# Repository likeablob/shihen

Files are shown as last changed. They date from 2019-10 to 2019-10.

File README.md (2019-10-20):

<p align="center">
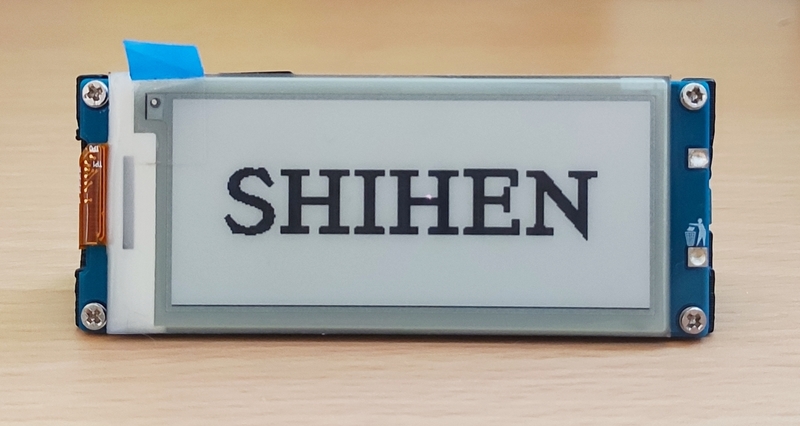
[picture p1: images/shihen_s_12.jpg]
  
</p>

**SHIHEN** is a device which colors your everyday (a bit).  
Have a glimpse of your favorite poems, quotes or scenes of a movie.

## Features
- On board RTC offers 2+ years of battery life.([in theory](https://blc.now.sh/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))
- By using [a dedicated Web-based converter](https://shihen.now.sh/), you can quickly show any texts and videos on the device.

## Gallery
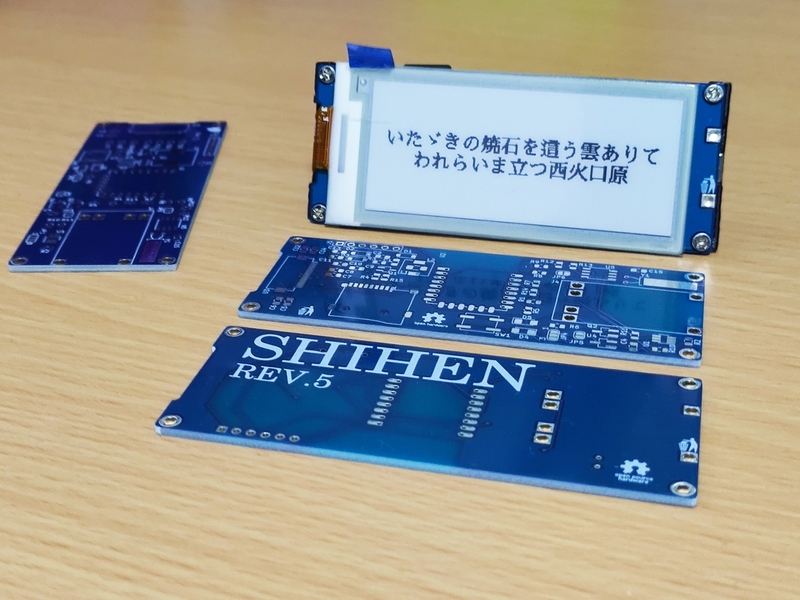
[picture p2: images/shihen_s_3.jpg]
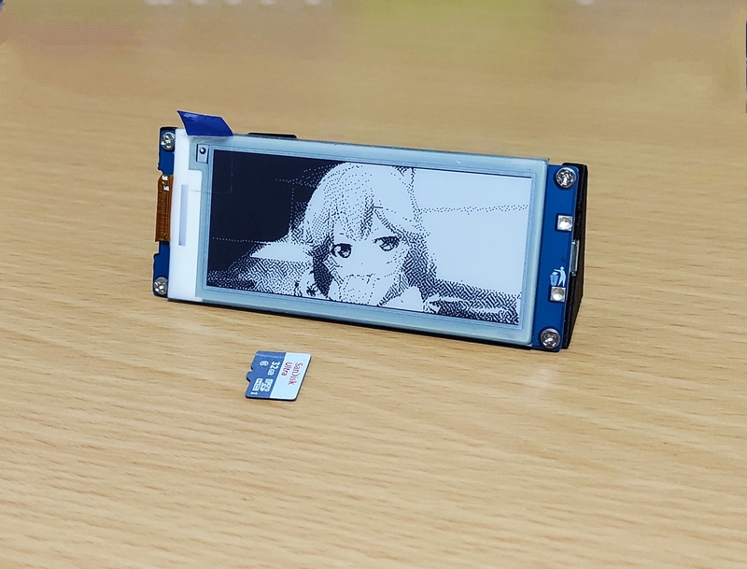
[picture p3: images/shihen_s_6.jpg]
|    |  |
| :---: | :---: |
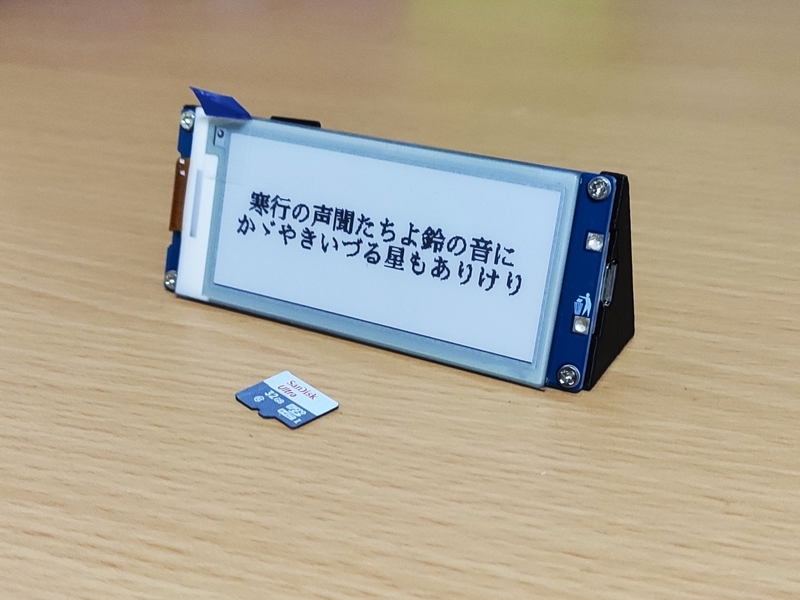
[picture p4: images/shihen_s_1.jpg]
|  |  |
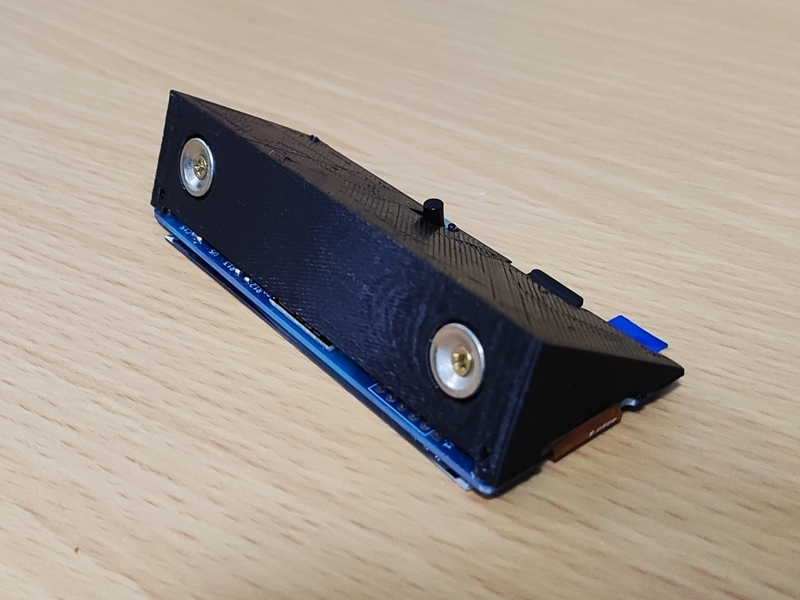
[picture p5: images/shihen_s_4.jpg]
|    | |

## Project structure
- [`pio/`](./pio) - code for the firmware(PlatformIO)
- [`kicad/`](./kicad) - PCB design (KiCad)
- [`openscad/`](./openscad) - models for the 3D-printable case. (OpenSCAD)
- https://github.com/likeablob/shihen-webui - code for the WebUI(Nuxt.js + Vuetify)

## Build Instructions
WIP

## BOM
WIP

## Refs
- Hackaday.io: https://hackaday.io/project/168039-shihen

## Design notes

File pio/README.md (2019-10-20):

# SHIHEN/firmware
It's built on top of [esp8266/Arduino](https://github.com/esp8266/Arduino).

## Prerequisites
- [PlatformIO](https://platformio.org/)

## Build
- `Ctrl+Alt+B` in your editor, or 
```bash
$ pio run
```

## Upload
- `Ctrl + Alt + U` in your editor, or 
```bash
$ pio run -t upload
```
- ***Tips:*** Don't forget to comment out the lines below to do ISP(UART) programming.
```bash
# platform.ini
upload_port = ${env:main.device_name}.local
upload_protocol = espota
```
### ISP port (J1) pin definitions:
| Pin No. | Board | USB Serial |
| --- | --- | --- |
| 1 | 5V(LDO_IN) | 5V |
| 2 | ESP_RESET(RST)  | RTS |
| 3 | ESP_BOOT(GPIO0) | DTR |
| 4 | GND | GND |
| 5 | ESP_TX(UART TX) | RX |
| 6 | ESP_RX(UART RX) | TX |

### Acknowledgments
- Please refer to
  - [platformio.ini](./platformio.ini)
  - [lib/](./lib)

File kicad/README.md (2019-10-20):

# SHIHEN/PCB

<p align="center">
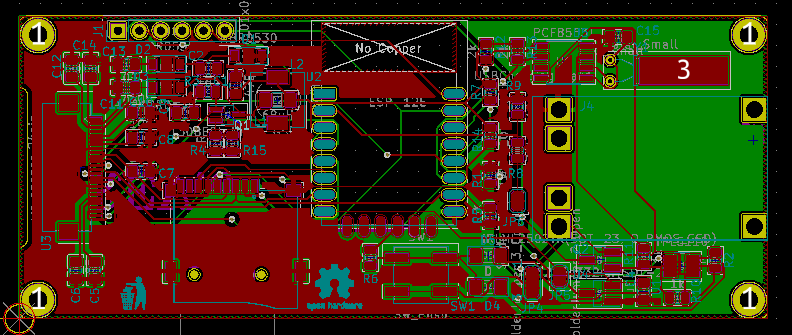
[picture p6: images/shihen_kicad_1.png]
  
</p>

## Prerequisites
- [KiCAD](http://kicad-pcb.org/) v5.0.1

## Credits
- [jdunmire]'s [ESP-12E.kicad_mod](./lib_ext/ESP-12E.kicad_mod): borrowed from [jdunmire/kicad-ESP8266](https://github.com/jdunmire/kicad-ESP8266/tree/70e6530de5e3cae4ae77a4bca7d73b20a0af6baf)
- [Joan_Sparky]'s [Conn_uSDcard.kicad_mod](./lib_ext/Conn_uSDcard.kicad_mod): borrowed from  https://forum.kicad.info/t/microsd-component-footprint-help/3095/5

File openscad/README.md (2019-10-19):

<p align="center">
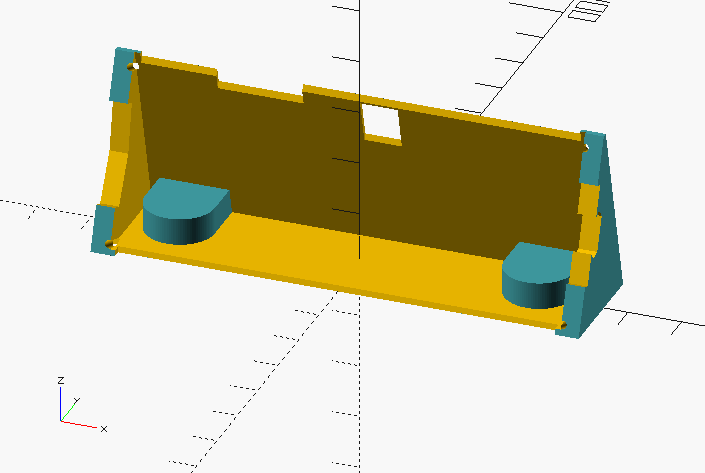
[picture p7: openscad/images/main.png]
  
</p>

## Print conditions
- PLA, 0.2 mm, 180 ℃
- `shihen-case` [[stl](./shihen-case.stl)]: Rotate so that the -YX(backbanel) plane is facing down.

## Dependencies
- openscad-nightly (`20181009T230242.gitf3de0e27+2416.1`)

## Build
```sh
$ make -j4
```

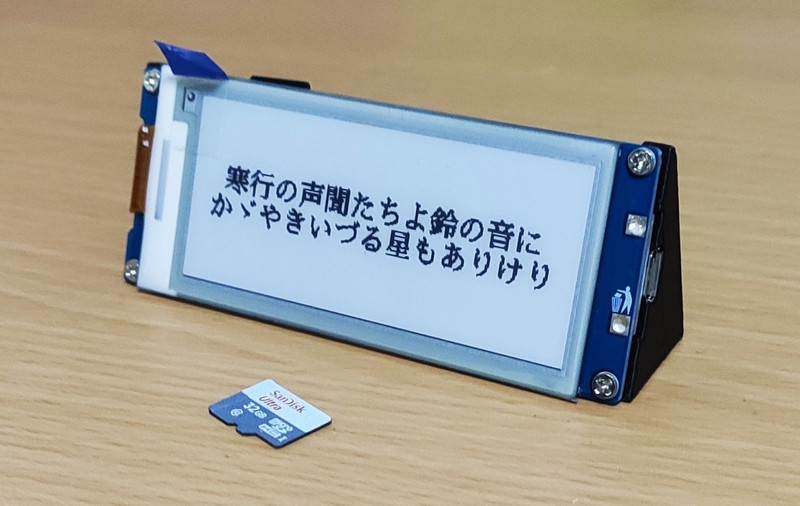
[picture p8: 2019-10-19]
images/shihen_s_1_tr.jpg

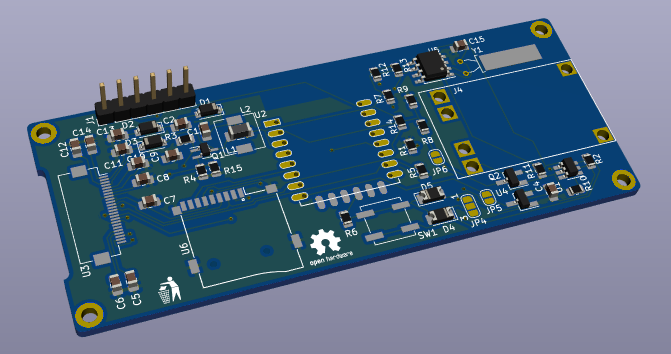
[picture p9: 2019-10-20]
images/shihen_kicad_2.png

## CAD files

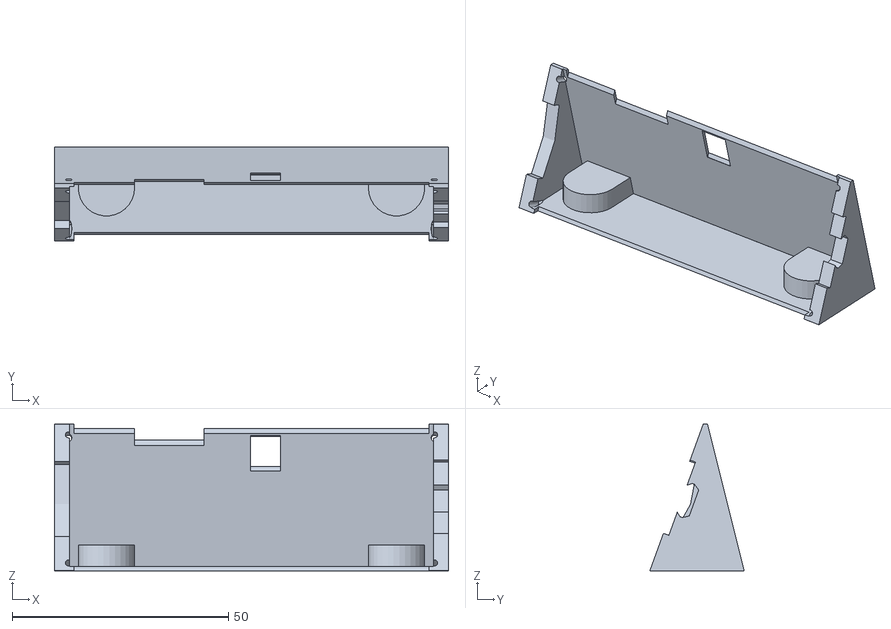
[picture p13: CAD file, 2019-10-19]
openscad/shihen-case.stl
91.0 x 21.8 x 33.8

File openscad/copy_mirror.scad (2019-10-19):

// Borrowed from http://forum.openscad.org/Wish-mirror-copy-true-td10681.html
module copy_mirror(vec=[0,1,0])
{
    children();
    mirror(vec) children();
}

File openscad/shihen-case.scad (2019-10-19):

$fn=30;

include <copy_mirror.scad>

BOARD_X = 83+2*2;
BOARD_Y = 27.5+2*2;

DISP_X=89;
DISP_Y=36;
DISP_Z=1.5;

DISP_E_X=68.3;
DISP_E_Y=30.5;

CASE_X=DISP_X+2;
CASE_Y=DISP_Y+2;
CASE_Z=DISP_Z+6;

SIDE_B_EDGE_Y=3.5*2;
SIDE_B_YPOS=4;

BOARD_ANGLE=80;

module display() {
  translate([0, 0, DISP_Z/2])
  cube(size=[DISP_X, DISP_Y, DISP_Z], center=true);

  translate([-DISP_X/2+DISP_E_X/2+7.2, 0, DISP_Z])
  color("green")
  cube(size=[DISP_E_X, DISP_E_Y, 0.1], center=true);
}

DISP_ANGLE=70;
*%translate([0, -DISP_Y*cos(DISP_ANGLE)/2-1, DISP_Y*sin(DISP_ANGLE)/2])
rotate([DISP_ANGLE, 0, 0])
display();

BAT_X=43;
BAT_Y=21.7;
BAT_Z=5.7;
// BAT
*%color("red")
translate([0, -(DISP_Y)*cos(DISP_ANGLE)/2+3, BAT_Y*sin(DISP_ANGLE)/2+6])
rotate([DISP_ANGLE, 0, 0])
cube(size=[BAT_X, BAT_Y, BAT_Z], center=true);

module caseBase(args) {
  hull() {
    translate([0, 0, DISP_Y*sin(DISP_ANGLE)])
    rotate([0, 90, 0])
    cylinder(d=0.01, h=CASE_X, center=true);

    translate([0, 1, DISP_Y*sin(DISP_ANGLE)])
    rotate([0, 90, 0])
    cylinder(d=0.01, h=CASE_X, center=true);

    translate([0, -DISP_Y*cos(DISP_ANGLE), 0])
    rotate([0, 90, 0])
    cylinder(d=0.01, h=CASE_X, center=true);

    translate([0, BOARD_Y*cos(BOARD_ANGLE)+SIDE_B_YPOS, 0])
    rotate([0, 90, 0])
    cylinder(d=0.01, h=CASE_X, center=true);
  }
}

module case() {
  difference() {
    union() {
      difference() {
        caseBase();

        // inner space
        translate([0, -1.0, 1])
        translate([0, 0, 0])
        resize([CASE_X-SIDE_B_EDGE_Y, 0, 0])
        caseBase();

        // display con
        CON_A_Z=3;
        translate([0, -DISP_Y*cos(DISP_ANGLE)/2-1, DISP_Y*sin(DISP_ANGLE)/2])
        rotate([DISP_ANGLE, 0, 0])
        translate([-(DISP_X/2-10/2)-1, 0, -CON_A_Z/2])
        hull() {
          cube(size=[10, 18.5, CON_A_Z], center=true);
          translate([0, 0, -CON_A_Z/2-1.5])
          rotate([0, 90, 0])
          cylinder(d=0.01, h=10, center=true);
        }

        // screw holes
        translate([0, -DISP_Y*cos(DISP_ANGLE)/2-1, DISP_Y*sin(DISP_ANGLE)/2])
        rotate([DISP_ANGLE, 0, 0])
        copy_mirror([1,0,0])
        copy_mirror([0,1,0])
        difference() {
          translate([DISP_X/2-2.25, -DISP_Y/2+2.25, -5])
          cylinder(d=1.5, h=CASE_Z, center=!true);
        }

        // push sw
        translate([0, -DISP_Y*cos(DISP_ANGLE)/2-1, DISP_Y*sin(DISP_ANGLE)/2])
        rotate([DISP_ANGLE, 0, 0])
        translate([-DISP_X/2+47.75, DISP_Y/2-5.25, 0])
        cube(size=[7, 7, CASE_Z*2], center=true);

        // sd slot
        translate([0, -DISP_Y*cos(DISP_ANGLE)/2-1, DISP_Y*sin(DISP_ANGLE)/2])
        rotate([DISP_ANGLE, 0, 0])
        translate([-DISP_X/2+25.5, DISP_Y/2, 0])
        cube(size=[16, 20, 8], center=true);
      }

      // magnet
      intersection() {
        resize([CASE_X-SIDE_B_EDGE_Y, 0, 0])
        caseBase();

        copy_mirror([1, 0, 0])
        translate([BOARD_X/2-10, 0, 0])
        hull() {
          cylinder(d=10+3, h=6, center=false);
          translate([0, (10+3), 6/2])
          cube(size=[10+3, 0.01, 6], center=true);
        }
      }

      // frame
  *    difference() {
        resize([CASE_X-SIDE_B_EDGE_Y, 0, 0])
        caseBase();
        translate([0, 0, BOARD_Y*sin(BOARD_ANGLE)/2+1])
        rotate([BOARD_ANGLE, 0, 0])
        resize([BOARD_X*2, BOARD_Y, 0])
        cylinder(d=1, h=40, center=true);
      }
    } // union

    // magnet
    copy_mirror([1, 0, 0])
    translate([BOARD_X/2-10, 0, -0.01])
    union() {
      cylinder(d=10+1, h=2.7, center=false);
      cylinder(d=1.5, h=6, center=false);
    }

    // edge
    translate([0, -DISP_Y*cos(DISP_ANGLE)/2, DISP_Y*sin(DISP_ANGLE)/2])
    rotate([DISP_ANGLE, 0, 0])
    translate([0, 0, -1/2])
    cube(size=[DISP_X-SIDE_B_EDGE_Y, DISP_Y+20, 2], center=true);

    // USB
    translate([0, -1, BOARD_Y*sin(BOARD_ANGLE)/2])
    rotate([DISP_ANGLE, 0, 0]) {

      translate([BOARD_X/2-5, -BOARD_Y/2+15.5, 4.5+1])
      rotate([0, 180, -90])
      USB_BOARD_DIF();

  *    translate([CASE_X/2-1, -BOARD_Y/2+14.8, 2])
      rotate([0, 90, 0])
      hull() {
        copy_mirror([0, 1, 0])
        translate([0, 7/2, 0])
        cylinder(d=7, h=10, center=!true);
      }
    }
  }
}

case();


USB_X = 18;
USB_Y = 15;
module USB_BOARD_DIF(scZ) {

  // BOARD
  difference() {
    translate([0, 0, 1.5/2])
    cube(size=[USB_X, USB_Y, 1.5], center=true);

    copy_mirror([1,0,0])
    translate([USB_X/2-3.3/2-1, -USB_Y/2+3.3/2+4, 0])
    cylinder(d=3.3, h=10, center=true);
  }

  // PORT
  USB_P_Y_OFFSET = 10;
  USB_P_Y = 8+USB_P_Y_OFFSET;
  translate([0, USB_Y/2-USB_P_Y/2 + USB_P_Y_OFFSET, 1.5-0.3]){
    hull() {
      // top
      translate([0, 0, 3.2])
      cube(size=[6.2+0.2, USB_P_Y, 0.01], center=true);

      // middle
      translate([0, 0, 1.55])
      cube(size=[8.0+0.2, USB_P_Y, 0.5], center=true);

      // bottom
      translate([0, 0, 0])
      cube(size=[5.2+1, USB_P_Y, 0.01], center=true);
    }
  }

  // screws
  copy_mirror([1,0,0])
  translate([USB_X/2-3.3/2-1, -USB_Y/2+3.3/2+4, -scZ/2])
  cylinder(d=2.2, h=scZ, center=true);
}

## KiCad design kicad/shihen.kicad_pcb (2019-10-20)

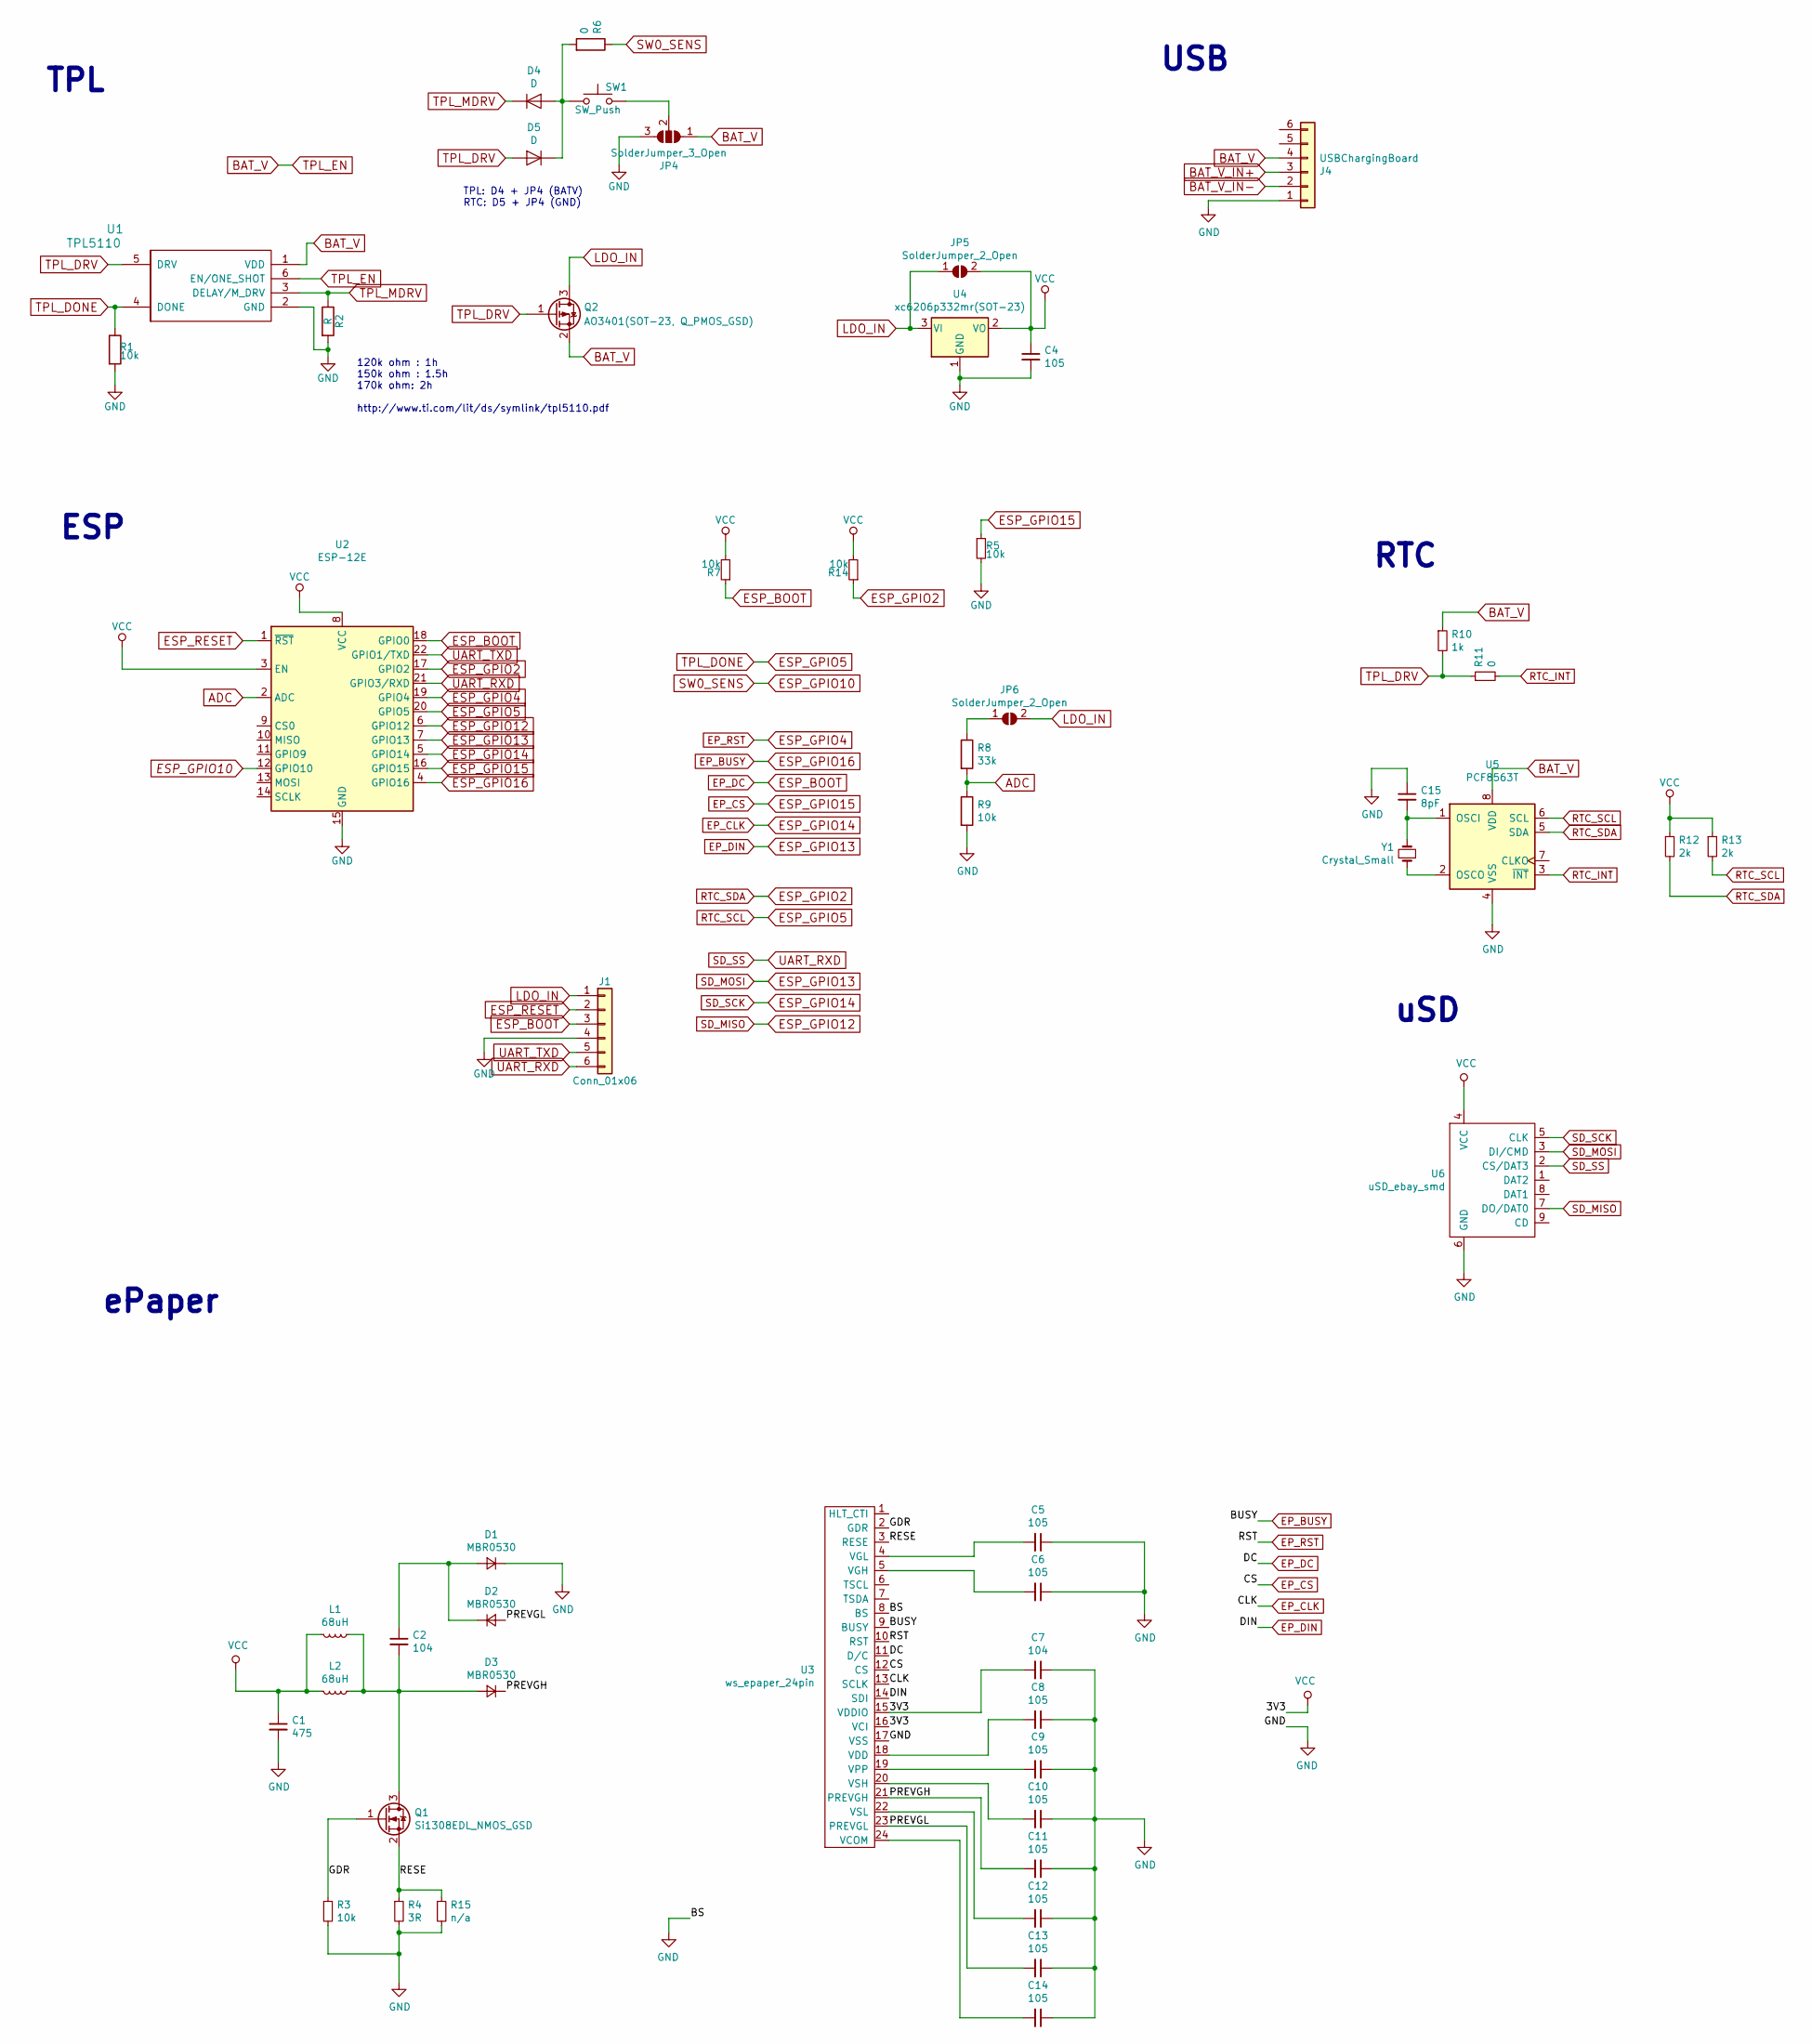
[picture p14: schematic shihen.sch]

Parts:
C1: 475; C_0805_2012Metric_Pad1.15x1.40mm_HandSolder; MPN CC0805KKX5R8BB475
C2, C7: 104; C_0805_2012Metric_Pad1.15x1.40mm_HandSolder; MPN C0805X104K101T
C4, C5, C6, C8, C9, C10, C11, C12, C13, C14: 105; C_0805_2012Metric_Pad1.15x1.40mm_HandSolder; MPN CC0805KKX7R8BB105
C15: 8pF; C_0805_2012Metric_Pad1.15x1.40mm_HandSolder; MPN 0805CG8R0C500NT
D1, D2, D3: MBR0530; D_SOD-123; MPN MBR0530
D4, D5: D; D_1206_3216Metric_Pad1.42x1.75mm_HandSolder; MPN LL4148ST
J1: Conn_01x06; PinHeader_1x06_P2.54mm_Vertical
J4: USBChargingBoard; USB_ChargingBoard
JP4: SolderJumper_3_Open; SolderJumper-3_P1.3mm_Open_RoundedPad1.0x1.5mm_NumberLabels
JP5, JP6: SolderJumper_2_Open; SolderJumper-2_P1.3mm_Open_RoundedPad1.0x1.5mm
L1: 68uH; L_6.3x6.3_H3
L2: 68uH; L_1206_3216Metric_Pad1.42x1.75mm_HandSolder; MPN NLCV32T-680K-PF
Q1: Si1308EDL_NMOS_GSD; SOT-323_SC-70_Handsoldering; MPN_disabled SI1308EDL-T1-GE3
Q2: AO3401(SOT-23, Q_PMOS_GSD); SOT-23_Handsoldering; MPN CJ2305
R1, R3, R5, R7, R9, R14: 10k; R_0805_2012Metric; MPN RC0805FR-0710KL
R2: R; R_0805_2012Metric
R4: 3R; R_0805_2012Metric; MPN 0805W8F300KT5E
R6, R11: 0; R_0805_2012Metric; MPN RC0805FR-070RL
R8: 33k; R_0805_2012Metric; MPN RC0805FR-0733KL
R10: 1k; R_0805_2012Metric; MPN RC0805JR-071KL
R12, R13: 2k; R_0805_2012Metric
R15: n/a; R_0805_2012Metric
SW1: SW_Push; SW_SPST_B3SL-1002P
U1: TPL5110; SOT-23-6_Handsoldering
U2: ESP-12E; MPN ESP-12E
U3: ws_epaper_24pin; Hirose_FH12-24S-0.5SH_1x24-1MP_P0.50mm_Horizontal_reverse; MPN FH12A-24S-0.5SH(55)
U4: xc6206p332mr(SOT-23); SOT-23_Handsoldering; MPN XC6206P332MR-G
U5: PCF8563T; SOIC-8_3.9x4.9mm_P1.27mm; MPN_disabled PCF8563T/5,518
U6: uSD_ebay_smd; Conn_uSDcard; MPN TF-01
Y1: Crystal_Small; Crystal_AT310_D3.0mm_L10.0mm_Horizontal_1EP_style1

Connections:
/GDR: Q1.1 (G), R3.1, U3.2 (GDR)
/PREVGH: C11.2, D3.1 (K), U3.21 (PREVGH)
/PREVGL: C13.2, D2.2 (A), U3.23 (PREVGL)
/RESE: Q1.2 (S), R4.1, R15.1, U3.3 (RESE)
ADC: R8.2, R9.1, U2.2 (ADC)
BAT_V: J4.4, JP4.1 (A), Q2.2 (S), R10.1, U1.1 (VDD), U1.6 (EN/ONE_SHOT), U5.8 (VDD)
BAT_V_IN+: J4.3
BAT_V_IN-: J4.2
EP_BUSY: U2.4 (GPIO16), U3.9 (BUSY)
EP_CLK: U2.5 (GPIO14), U3.13 (SCLK), U6.5 (CLK)
EP_CS: R5.1, U2.16 (GPIO15), U3.12 (CS)
EP_DC: J1.3, R7.1, U2.18 (GPIO0), U3.11 (D/C)
EP_DIN: U2.7 (GPIO13), U3.14 (SDI), U6.3 (DI/CMD)
EP_RST: U2.19 (GPIO4), U3.10 (RST)
ESP_GPIO2: R12.2, R14.1, U2.17 (GPIO2), U5.5 (SDA)
ESP_GPIO5: R1.1, R13.2, U1.4 (DONE), U2.20 (GPIO5), U5.6 (SCL)
ESP_GPIO10: R6.1, U2.12 (GPIO10)
ESP_GPIO12: U2.6 (GPIO12), U6.7 (DO/DAT0)
ESP_RESET: J1.2, U2.1 (~RST)
GND: C1.2, C4.2, C5.1, C6.1, C7.1, C8.1, C9.1, C10.1, C11.1, C12.1, C13.1, C14.1, C15.1, D1.1 (K), J1.4, J4.1, JP4.3 (B), R1.2, R2.2, R3.2, R4.2, R5.2, R9.2, R15.2, U1.2 (GND), U2.15 (GND), U3.8 (BS), U3.17 (VSS), U4.1 (GND), U5.4 (VSS), U6.6 (GND)
LDO_IN: J1.1, JP5.1 (A), JP6.2 (B), Q2.3 (D), U4.3 (VI)
unnamed: C2.1, D1.2 (A), D2.1 (K)
unnamed: C2.2, D3.2 (A), L1.1, L2.1, Q1.3 (D)
unnamed: C5.2, U3.4 (VGL)
unnamed: C6.2, U3.5 (VGH)
unnamed: C8.2, U3.18 (VDD)
unnamed: C9.2, U3.19 (VPP)
unnamed: C10.2, U3.20 (VSH)
unnamed: C12.2, U3.22 (VSL)
unnamed: C14.2, U3.24 (VCOM)
unnamed: C15.2, U5.1 (OSCI), Y1.2
unnamed: D4.2 (A), D5.1 (K), R6.2, SW1.1
unnamed: JP4.2 (C), SW1.2
unnamed: JP6.1 (A), R8.1
unnamed: U5.2 (OSCO), Y1.1
RTC_INT: R11.2, U5.3 (~INT~)
SD_SS: J1.6, U2.21 (GPIO3/RXD), U6.2 (CS/DAT3)
TPL_DRV: D5.2 (A), Q2.1 (G), R10.2, R11.1, U1.5 (DRV)
TPL_MDRV: D4.1 (K), R2.1, U1.3 (DELAY/M_DRV)
UART_TXD: J1.5, U2.22 (GPIO1/TXD)
VCC: C1.1, C4.1, C7.2, JP5.2 (B), L1.2, L2.2, R7.2, R12.1, R13.1, R14.2, U2.3 (EN), U2.8 (VCC), U3.15 (VDDIO), U3.16 (VCI), U4.2 (VO), U6.4 (VCC)

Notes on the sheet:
120k ohm : 1h 150k ohm : 1.5h 170k ohm: 2h http://www.ti.com/lit/ds/symlink/tpl5110.pdf
TPL: D4 + JP4 (BATV) RTC: D5 + JP4 (GND)
TPL
ESP
ePaper
USB
RTC
uSD

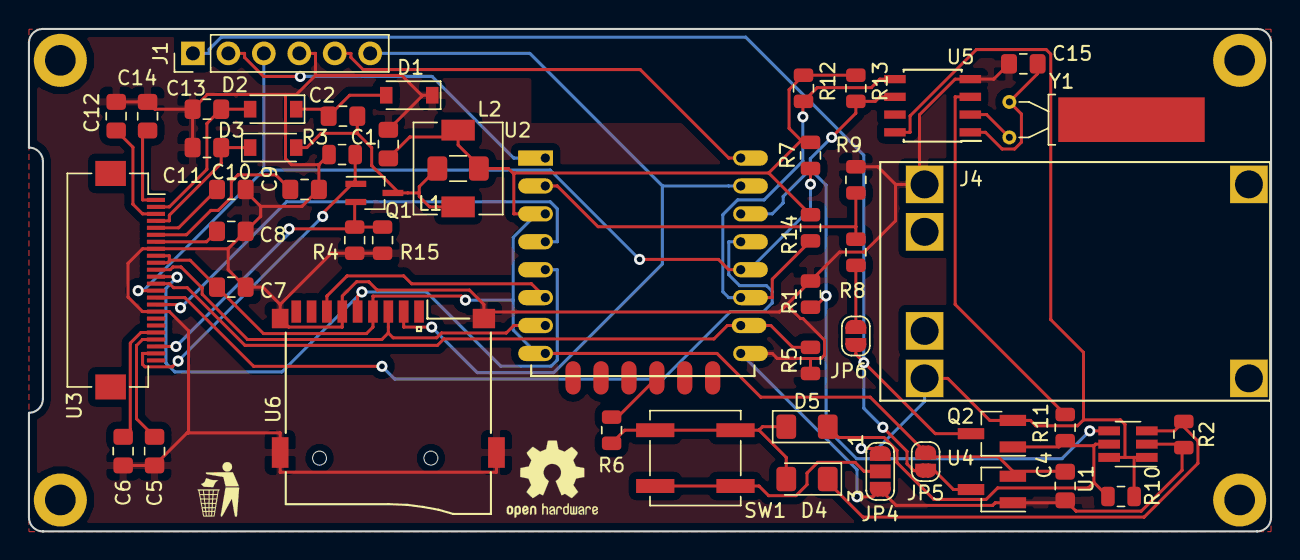
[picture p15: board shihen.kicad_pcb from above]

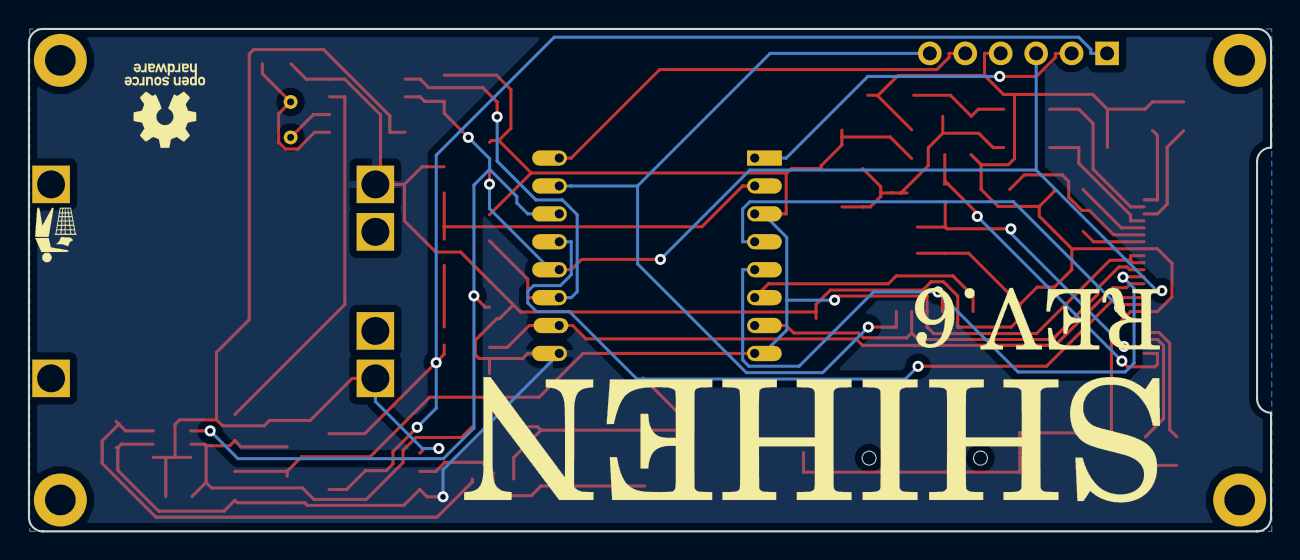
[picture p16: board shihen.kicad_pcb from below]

Board: 2 copper layers, 89.0 x 36.0 mm, 59 parts (3 on the bottom side), 39 nets.

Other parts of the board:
G1, G3: LOGO; gomi_5.7x5.7
G2: LOGO; shihen_logo_53x10
G4: OSHW-Logo_5.7x6mm_SilkScreen
MH1, MH2, MH3, MH4: MountingHole_2.2mm_M2_DIN965_Pad

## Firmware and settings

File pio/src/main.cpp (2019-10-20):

#include <Arduino.h>

#include <ESP8266WebServer.h>
#include <ESP8266WiFi.h>
#include <WiFiManager.h>
WiFiManager wifiManager;
ESP8266WebServer server(80);

#include <Chrono.h>

extern "C" {
#include "user_interface.h"
}

#include "config.h"
#include "display.h"
#include "ota.h"
#include "pm.h"
#include "rtc.h"
#include "settings.h"
#include "storage.h"
#include "utils.h"

void showModeInfo(String title) {
    display1.fillScreen(GxEPD_WHITE);
    display1.setTextColor(GxEPD_BLACK);
    display1.setFont(&FreeMonoBold18pt7b);
    display1.setCursor(2, 24 + 2);
    display1.println(title);
    display1.setFont(&FreeMonoBold9pt7b);

    display1.setCursor(0, 24 + 18 + 4);
    display1.print(" Image id:");
    display1.printf("%d", deviceSettings.imageId);
    display1.println();

    // display1.print(" Boot count:");
    // display1.printf("%d%%%d", deviceSettings.bootCount,
    //                           deviceSettings.refreshInterval);

#ifdef USE_RTC
    display1.print(" Time:");
    bcddatetime_t bcddatetime = RTC.now();
    Serial.print(bcddatetime.date, HEX);
    Serial.write(' ');
    Serial.print(bcdTimeToTimeString(bcddatetime.time));
    Serial.println();
    Serial.println(bcddatetime.time, HEX);
    display1.print(bcdTimeToTimeString(bcddatetime.time));
    display1.println();
#endif

    // display1.print(" repo:");
    // display1.print(deviceSettings.repository);
    // display1.println();
    //
    // display1.print(" orientation:");
    // display1.print(deviceSettings.orientation);
    // display1.println();

    float batV, batVFraction;
    getBatteryVoltage(&batV, &batVFraction);

    display1.print(" Vbat:");
    display1.printf("%.2fV", batV);
    display1.printf("(%d%%)", (int)(batVFraction * 100));
    display1.println();

    display1.print(" AP:");
    String apName = WiFi.SSID();
    display1.print(apName.length() ? apName : DEVICE_NAME);
    display1.println();

    display1.print(" IP:");
    display1.print(WiFi.localIP());
    display1.println();
}

void startWiFiManager() {
    showModeInfo("AP Mode");
    display1.updateWindow(1, 1, DISP_HEIGHT - 2, DISP_WIDTH - 2);
    wifiManager.setTimeout(120);
    WiFiManagerParameter orientation("Orientation", "3", "3", 2);
    WiFiManagerParameter refreshInterval("Refresh interval(N*2h)", "6", "6", 2);
    wifiManager.addParameter(&orientation);
    wifiManager.addParameter(&refreshInterval);
    if(!wifiManager.startConfigPortal(DEVICE_NAME)) {
        Serial.println("Timeout! Failed to connect");
        drawMessage("Timeout");
        display1.updateWindow(1, 1, DISP_HEIGHT - 2, DISP_WIDTH - 2);
        powerManagementService.shutdown();
    }

    deviceSettings.orientation = atoi(orientation.getValue());
    deviceSettings.refreshInterval = atoi(refreshInterval.getValue());
    settingsService.saveSettings();
}

uint32_t otaStart = 0;
void setup() {
    WiFi.forceSleepBegin();
    Serial.begin(115200);
    Serial.println("setup");

    powerManagementService.begin();

    settingsService.begin();
    settingsService.loadBootCount();
    settingsService.loadSettings();
    //     uint8_t sw0StateA = readSw0();
    // if (bootCount % 6 != 0 && !sw0StateA) {
    //   shutdown();
    // }

#if BOARD_REVISION == 6
    pinMode(PIN_DISP_RST, OUTPUT);
    digitalWrite(PIN_DISP_RST, LOW);
    delay(10);
    digitalWrite(PIN_DISP_RST, HIGH);
    delay(10);
#endif

    display1.init();
    display1.setRotation(3);

    bool storageInitialized = storageService.begin();
#ifdef USE_SD
    if(!storageInitialized) {
        Serial.print("SD init failed");
        drawMessage("SD init failed");
        delay(1000);
        ESP.reset();
    }
#endif

    // Read battery voltage
    float batV, batVFraction;
    getBatteryVoltage(&batV, &batVFraction);

    //  Read and draw an image
    uint16_t imageId = deviceSettings.imageId;
    img_read_err_t readRes = drawImage(imageId);
    Serial.print("readRes:");
    Serial.println(readRes);
    if(readRes <= IMG_READ_OK_LAST_IMG) {
        display1.drawFastHLine(0, DISP_WIDTH - 1, batVFraction * DISP_HEIGHT,
                               GxEPD_BLACK);
        display1.update();

#ifdef USE_BWR_PANEL
        if(readRes == IMG_READ_OK_LAST_IMG) {
            imageId = 0;
        } else {
            imageId += 2;
            deviceSettings.imageId = imageId; // next imageId
        }
#else
        if(readRes == IMG_READ_OK_LAST_IMG) {
            imageId = 0;
        } else {
            imageId++;
        }
        while(powerManagementService.readSw0()) { // fast forwarding
            readRes = drawImage(imageId++);
            if(readRes >= IMG_READ_OK_LAST_IMG) {
                imageId = 0;
            }
            if(readRes > IMG_READ_OK_LAST_IMG) {
                break;
            }
            display1.updateWindow(
                1, 1, DISP_HEIGHT - 2,
                DISP_WIDTH - 2); // FIXME: workaround for partial updating
            if(!powerManagementService.readSw0()) {
                display1.drawFastHLine(0, DISP_WIDTH - 1,
                                       batVFraction * DISP_HEIGHT, GxEPD_BLACK);
                display1.update();
                delay(500);
                break;
            }
        }
        deviceSettings.imageId = imageId; // next imageId
#endif
    } else {
        deviceSettings.imageId = 0;
    }

    settingsService.saveSettings();

    bool sw0StateB = powerManagementService.readSw0();
    if(sw0StateB) {
        WiFi.forceSleepWake();
        delay(1);
        WiFi.mode(WIFI_STA);
        wifi_station_connect();
        WiFi.begin();
        drawMessage("OTAMode");
        display1.updateWindow(1, 1, DISP_HEIGHT - 2,
                              DISP_WIDTH -
                                  2); // FIXME: workaround for partial updating

        int16_t count = 100;
        while(--count) { // Wait connection for 10 sec at max
            delay(100);
            if(WiFi.isConnected()) {
                break;
            }
        }
        if(!count) {
            Serial.println("startWifiManager");
            startWiFiManager();
        }

        deviceSettings.imageId = 0;
        settingsService.saveSettings();

        powerManagementService.syncTime();
        setupOTA();
#ifdef USE_SPIFFS
        fileServer.begin(&server);
#endif
        server.begin();
        showModeInfo("OTA Mode");
        display1.updateWindow(0, 0, DISP_HEIGHT - 1, DISP_WIDTH - 1);
    } else {
        powerManagementService.shutdown();
    }
    otaStart = millis();
}

Chrono refreshTask;
#define PUSH_DURATION_SHORT 3000 // 3 sec
#define PUSH_DURATION_LONG 5000  // 5 sec
void loop() {
    static uint16_t refreshCount = 0;
    static uint32_t pushStart = 0;

    handleOTA();
    server.handleClient();

    if(!refreshCount && powerManagementService.readSw0()) {
        return; // skip the following until the switch is released
    }

    if(refreshTask.hasPassed(3000)) {
        refreshTask.restart();
        refreshCount++;
        String msg = "Btn>";
        if(pushStart > 0) {
            uint32_t pushDuration = millis() - pushStart;
            if(pushDuration < PUSH_DURATION_SHORT) {
                msg = "Exit";
            } else if(PUSH_DURATION_LONG < pushDuration) {
                msg = "Reset";
            }
        }

        showModeInfo("OTA Mode");
        uint16_t bg = refreshCount % 2 ? GxEPD_BLACK : GxEPD_WHITE;
        uint16_t fg = refreshCount % 2 ? GxEPD_WHITE : GxEPD_BLACK;
        drawToast(msg, fg, bg);

#ifdef USE_BWR_PANEL
        // FIXME: no way to update due to slow refresh rate
#else
        display1.updateWindow(1, 1, DISP_HEIGHT - 2, DISP_WIDTH - 2);
#endif
    }

    // read the switch's state
    if(pushStart == 0 && powerManagementService.readSw0()) {
        pushStart = millis();
    } else if(pushStart > 0 && !powerManagementService.readSw0()) {
        uint32_t pushDuration = millis() - pushStart;
        if(pushDuration < PUSH_DURATION_SHORT) {
            drawMessage("Exitting..");
            display1.updateWindow(1, 1, DISP_HEIGHT - 2, DISP_WIDTH - 2);
            delay(500);
            display1.eraseDisplay(true);
            powerManagementService.shutdown();
        } else if(PUSH_DURATION_LONG < pushDuration) {
            drawMessage("Resetting");
            display1.updateWindow(1, 1, DISP_HEIGHT - 2, DISP_WIDTH - 2);
            wifiManager.resetSettings();
            powerManagementService.shutdown();
        }
        pushStart = 0;
    }
}

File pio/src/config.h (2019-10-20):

#pragma once
#ifndef INCLUDE_GUARD_CONFIG_H
#define INCLUDE_GUARD_CONFIG_H

/* Configuration flags */
#define USE_SD
// #define USE_SPIFFS

#define USE_RTC
// #define USE_TPL

// #define USE_BWR_PANEL

/* Other */
#define TIME_ZONE 9
// WAKE_TIME_TABLE, bitN : Wake up flag for N o'clock
// e.g 0x400001 : Wake up at AM 00:00 and PM 10:00 : (1 << 22 | 1)
// e.g 0xFFFFFF : Wake up at AM 00:00 and PM 11:00
#define WAKE_TIME_TABLE 0xFFFFFF
#define DISP_WIDTH 128
#define DISP_HEIGHT 296

#define BOARD_REVISION 6
#if BOARD_REVISION == 5
#define BOARD_REVISION_STR "rev.5"
#elif BOARD_REVISION == 6
#define BOARD_REVISION_STR "rev.6"
#endif

/* PIN definitions */
#if BOARD_REVISION == 5
#define PIN_SW0_SENS 4

#define PIN_TPL_DONE 5

#define PIN_DISP_MOSI 13 // not used
#define PIN_DISP_MISO 12 // not used
#define PIN_DISP_SCK 14  // not used
#define PIN_DISP_CS 15
#define PIN_DISP_DC 0
#define PIN_DISP_BUSY 16
#define PIN_DISP_RST 2

#define PIN_SD_MOSI 13 // not used
#define PIN_SD_MISO 12 // not used
#define PIN_SD_SCK 14  // not used
#define PIN_SD_CS 3    // UART RX

#define PIN_RTC_SDA 2
#define PIN_RTC_SCL 5
#elif BOARD_REVISION == 6
#define PIN_SW0_SENS 10

#define PIN_TPL_DONE 5

#define PIN_DISP_MOSI 13 // not used
#define PIN_DISP_MISO 12 // not used
#define PIN_DISP_SCK 14  // not used
#define PIN_DISP_CS 15
#define PIN_DISP_DC 0
#define PIN_DISP_BUSY 16
#define PIN_DISP_RST 4

#define PIN_SD_MOSI 13 // not used
#define PIN_SD_MISO 12 // not used
#define PIN_SD_SCK 14  // not used
#define PIN_SD_CS 3    // UART RX

#define PIN_RTC_SDA 2
#define PIN_RTC_SCL 5

#endif

#endif // INCLUDE_GUARD_CONFIG_H

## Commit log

2019-10-19 Add OpenSCAD files
    [copy_mirror.scad, shihen-case.scad, shihen-case.stl]
2019-10-20 Add KiCad, gerber files
    [shihen.kicad_pcb, shihen.sch]
2019-10-20 Modify schemas - Add MPN(Fusion PCB's part number) as an attribute for PCBA - Fix some wrong constants
    [shihen.kicad_pcb, shihen.sch]
